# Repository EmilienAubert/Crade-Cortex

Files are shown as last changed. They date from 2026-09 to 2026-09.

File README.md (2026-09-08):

# Crade Cortex

**English** · [Français](README.fr.md)

A DIY MIDI footswitch controller for [PiPedal](https://github.com/rerdavies/pipedal)
with **closed-loop state feedback**: the LEDs and display don't show what your
foot asked for, they show what the Raspberry Pi confirmed.

A Pico running CircuitPython sends MIDI. A Python daemon on the Pi subscribes to
PiPedal's websocket and pushes state back over the same USB cable. One state
exists — PiPedal's — and the whole class of desynchronisation bugs disappears by
construction.

**3D files (.STL and .SLDPRT) are availables in the repo.**

This repository also contains 
[documentation of PiPedal's undocumented internal websocket protocol](docs/en/PROTOCOL.md),
reverse-engineered from version 2.0.110. That is probably the most reusable part
of it for other projects.




---

## What it does

- **4 snapshots** with exclusive selection, confirmed by the Pi
- **Preset changes** with the LED held lit through the NAM model load
- **Tuner** on the display — note and cents, subscribed only on demand
- **16×2 LCD** — pedalboard and snapshot names, boot animation
- **Dead-link detection** — blinking LEDs and an on-screen marker

```
              MIDI CC 102-113 (USB MIDI -> ALSA)
        ┌──────────────────────────────────────────────┐
        │                                              ▼
   ┌─────────┐          ┌──────────────────┐      ┌──────────┐
   │  Pedal  │◄────────►│ pipedal_bridge.py│◄─────│ pipedald │
   │  Pico   │  serial  │     (daemon)     │  ws  │ (PiPedal)│
   └─────────┘          └──────────────────┘      └──────────┘
    S3  N:  T:              A1  A0  ?
```

MIDI does **not** go through the daemon: the Pico talks straight to `pipedald`
via ALSA. The daemon only handles the return path.

---

## Hardware

| Item | Detail |
|---|---|
| Controller | Raspberry Pi Pico (RP2040), CircuitPython |
| Host | Raspberry Pi, PiPedal 2.0.110 |
| Display | LCD1602, HD44780, 4-bit mode |
| Switches | 8 SPST momentary footswitches |
| LEDs | 8, PWM at 2 kHz, one resistor each |

Full wiring, pinout and assembly order: **[docs/en/WIRING.md](docs/en/WIRING.md)**

---

## Installation

### On the Pico

#### 1. Install CircuitPython

Download the `.uf2` for the Raspberry Pi Pico from
[circuitpython.org](https://circuitpython.org/board/raspberry_pi_pico/).

Hold **BOOTSEL** down **before** plugging in the USB cable, then release it. An
`RPI-RP2` drive appears. Drop the `.uf2` onto it: the Pico reboots on its own and
a `CIRCUITPY` drive takes its place.

If the Pico was running different firmware, or if the major version changes, the
install can leave an inconsistent filesystem. In that case run
[`flash_nuke.uf2`](https://learn.adafruit.com/circuitpython-with-raspberry-pi-pico/resetting-flash)
first to wipe the flash completely.

#### 2. Install the libraries

Download the [CircuitPython bundle](https://circuitpython.org/libraries) —
**the one matching your installed major version**. A 9.x bundle on 10.x firmware
produces import errors that are hard to diagnose. The version is written in
`boot_out.txt` at the root of `CIRCUITPY`.

Copy these two folders into `/lib`:

```
lib/
  adafruit_midi/              USB MIDI
  adafruit_character_lcd/     HD44780 driver
```

Whole folders, not just the `.py` files you think you need.

#### 3. Copy the project

To the root of `CIRCUITPY`:

```
boot.py  code.py  ecran.py  retour_pipedal.py
```

On Linux, run `sync` before unplugging. The `CIRCUITPY` filesystem is small and
corrupts easily if a write hasn't finished.

#### 4. Restart

`boot.py` is only re-read on a **hard reset**: unplug and plug back in. Saving
the file is not enough — that's the classic trap.

Saving `code.py`, on the other hand, restarts the program automatically.

#### Checking

`boot_out.txt` holds the CircuitPython version and, when something goes wrong,
the reason it dropped into safe mode. It's the first place to look if the display
stays dark or nothing starts.

```bash
ls /dev/ttyACM*        # two ports should appear: console and data
```

### On the Raspberry Pi

```bash
sudo apt install python3-serial
pip3 install websockets --break-system-packages
```

A udev rule for a stable port name — without it, the `ttyACM` number changes with
plug order:

```
# /etc/udev/rules.d/99-pipedal-pico.rules
SUBSYSTEM=="tty", ATTRS{idVendor}=="239a", ATTRS{product}=="Pedalier", \
  ENV{ID_USB_INTERFACE_NUM}=="02", SYMLINK+="pipedal-pico"
```

```bash
sudo udevadm control --reload && sudo udevadm trigger
python3 pi/pipedal_bridge.py -v
```

A sample systemd unit is provided in `pi/pipedal-bridge.service`.

### MIDI bindings in PiPedal

| System symbol | CC |
|---|---|
| `snapshot1` … `snapshot4` | 102 … 105 |
| `prevProgram` | 110 |
| `nextProgram` | 111 |

CC 112 drives the tuner locally. Binding it to the TooB Tuner's `MUTE` control
lets one press both mute the signal and bring up the tuner.

---

## Documentation

| Document | Contents |
|---|---|
| [docs/en/PROTOCOL.md](docs/en/PROTOCOL.md) | **PiPedal's websocket protocol**, reverse-engineered |
| [docs/en/WIRING.md](docs/en/WIRING.md) | Pinout, wiring, assembly order, checks |
| [docs/en/index.html](docs/en/index.html) | Full documentation, laid out |

---

## The principle

> PiPedal is the single source of truth. The Pico holds no state of its own.

Pressing a switch sends a CC, nothing more. The LED only lights when the Pi's
confirmation arrives. That's what keeps the display honest whatever caused the
change — your foot, the phone, or a `pipedald` restart.

Two safeguards cover link failure, because a closed loop that opens would leave
the LEDs frozen on the last value received:

- **Optimistic fallback at 200 ms** — with no confirmation, the LED lights
  anyway. Degraded, but playable.
- **Heartbeat at 1 Hz** — three missed beats and the active LED blinks, with a
  `!` on the display.

---

## Serial protocol

One ASCII line per event, bidirectional.

| Direction | Frame | Meaning |
|---|---|---|
| Pi → Pico | `S<n>` | Active snapshot, 1-based |
| | `HB` | Heartbeat |
| | `N:<text>` | Pedalboard name |
| | `M:<text>` | Snapshot name |
| | `T:<note>:<cents>` | Tuner |
| Pico → Pi | `A1` / `A0` | Enter / leave tuner mode |
| | `?` | Request full state |

The `?` beacon deserves an explanation: the daemon caches state and only emits on
change. When the Pico restarts, nothing has changed on PiPedal's side — without
this explicit request the pedal would stay blind until the next real change.

---

## Tools

`outils/banc_test_led.py` — a test bench to copy onto a second Pico. Three
looping phases: all LEDs at real brightness so you can match channels, a chase to
identify positions, and full brightness to spot a dead or reversed LED.

Rename it to `code.py` on the test Pico.

---

## A warning about the websocket protocol

PiPedal's websocket API is **internal and undocumented**. This repository
publishes a description captured from version **2.0.110**. It will change between
versions, without notice, and that won't be a bug on PiPedal's side.

If you build on it, pin yourself to a known version and plan to re-verify after
every update.

---

## Licence

MIT. See [LICENSE](LICENSE).

Developed with assistance from Claude (Anthropic). The architecture, the protocol
reverse-engineering and the engineering trade-offs came out of iterative work
between a human and the model.

Source comments are in French.

---

## Acknowledgements

[Robin Davies](https://github.com/rerdavies) for PiPedal, which runs a serious
effects processor on a Raspberry Pi, and whose architecture — a single
server-side model broadcast to every client — is what makes this kind of project
possible at all.

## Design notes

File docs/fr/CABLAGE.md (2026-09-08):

# Crade Cortex — schéma de câblage

[English](../en/WIRING.md) · **Français**

Établi d'après `code.py`. Toute modification d'affectation dans le code doit
être reportée ici, et inversement.

---

## 1. Brochage physique du Pico

Le Pico a 40 broches. La 1 est en haut à gauche, connecteur USB vers le haut.
La numérotation descend à gauche jusqu'à 20, puis remonte à droite de 21 à 40.

```
                    ┌───── USB ─────┐
      S1   GP0  ────┤ 1          40 ├──── VBUS  → LCD 2 et 15
      S2   GP1  ────┤ 2          39 │     VSYS
           GND      │ 3          38 ├──── GND   → rail de masse
      S3   GP2  ────┤ 4          37 │     3V3_EN
      S4   GP3  ────┤ 5          36 │     3V3 OUT   (ne pas utiliser)
    Prst-  GP4  ────┤ 6          35 │     ADC_VREF
    Prst+  GP5  ────┤ 7          34 │     GP28
           GND      │ 8          33 │     AGND
    Accord GP6  ────┤ 9          32 │     GP27
    Libre  GP7  ────┤ 10         31 │     GP26
    LED1   GP8  ────┤ 11         30 │     RUN
    LED2   GP9  ────┤ 12         29 │     GP22
           GND      │ 13         28 │     GND
  LCD RS   GP10 ────┤ 14         27 ├──── GP21   LED8
  LCD E    GP11 ────┤ 15         26 ├──── GP20   LED7
  LCD D4   GP12 ────┤ 16         25 ├──── GP19   LED6
  LCD D5   GP13 ────┤ 17         24 ├──── GP18   LED5
           GND      │ 18         23 │     GND
  LCD D6   GP14 ────┤ 19         22 ├──── GP17   LED4
  LCD D7   GP15 ────┤ 20         21 ├──── GP16   LED3
                    └───────────────┘
```

**22 broches utilisées sur 26 disponibles.** Restent libres : `GP22`, `GP26`,
`GP27`, `GP28`.

> **Ne jamais alimenter le LCD depuis la broche 36 (3V3).** Il lui faut du 5 V,
> donc la broche 40 (VBUS). Un HD44780 en 3,3 V ne s'allume pas ou affiche
> n'importe quoi.

---

## 2. Table de correspondance

| GPIO | Broche physique | Fonction |
|---|---|---|
| `GP0` | 1 | Switch S1 |
| `GP1` | 2 | Switch S2 |
| `GP2` | 4 | Switch S3 |
| `GP3` | 5 | Switch S4 |
| `GP4` | 6 | Switch F1 — preset précédent |
| `GP5` | 7 | Switch F2 — preset suivant |
| `GP6` | 9 | Switch F3 — accordeur |
| `GP7` | 10 | Switch F4 — libre |
| `GP8` | 11 | LED 1 |
| `GP9` | 12 | LED 2 |
| `GP10` | 14 | LCD — RS |
| `GP11` | 15 | LCD — E |
| `GP12` | 16 | LCD — D4 |
| `GP13` | 17 | LCD — D5 |
| `GP14` | 19 | LCD — D6 |
| `GP15` | 20 | LCD — D7 |
| `GP16` | 21 | LED 3 |
| `GP17` | 22 | LED 4 |
| `GP18` | 24 | LED 5 |
| `GP19` | 25 | LED 6 |
| `GP20` | 26 | LED 7 |
| `GP21` | 27 | LED 8 |
| — | 38 | GND — rail de masse |
| — | 40 | VBUS — 5 V vers le LCD |

LED 1 et 2 sont à gauche, LED 3 à 8 à droite : c'est un héritage du câblage
initial sur `GP8`/`GP9`. Les déplacer ne servirait qu'à l'esthétique du faisceau,
et obligerait à recâbler ce qui fonctionne déjà.

---

## 2 bis. Disposition sur la face

Deux rangées de quatre, de gauche à droite. Le rang avant est celui qu'on
utilise le plus : il doit être le plus proche du bord.

```
   arriere   [ Preset - ] [ Preset + ] [ Accordeur ] [ Libre ]
                 GP4          GP5          GP6         GP7
                 CC 110       CC 111       CC 112      CC 113

   avant     [    S1    ] [    S2    ] [    S3     ] [   S4   ]
                 GP0          GP1          GP2         GP3
                 CC 102       CC 103       CC 104      CC 105
```

**Les LED se placent au-dessus des switches, jamais en dessous.** Le pied masque
la zone basse pendant l'appui : une LED sous le switch n'est visible qu'une fois
le pied retiré, c'est-à-dire trop tard.

**Au moins 25 mm entre les axes des deux rangées**, 40 mm si la place le permet.
En dessous, le talon accroche le rang arrière quand on appuie sur le rang avant.

Le boîtier passe de 27 mm à l'avant à 63 mm à l'arrière. Le rang arrière tombe
donc sur une zone plus épaisse et plus inclinée : vérifie qu'il reste assez de
hauteur sous la face pour le corps du footswitch et ses cosses, souvent 25 à
30 mm avec le fil.

### Bindings PiPedal correspondants

| Symbole système | CC |
|---|---|
| `snapshot1` … `snapshot4` | 102 … 105 |
| `prevProgram` | 110 |
| `nextProgram` | 111 |

Optionnel : lier le CC 112 au contrôle `MUTE` du TooB Tuner, pour couper le son
et afficher l'accordeur d'un seul geste.

---

## 3. Le rail de masse

Dix-neuf connexions vont à la masse : huit switches, huit LED, trois broches du
LCD. Les souder toutes sur la broche 38 est impossible.

**Fabrique un rail.** Un fil de cuivre nu, ou une piste de plaque à trous,
courant sur toute la longueur du montage. Une seule liaison le relie à la
broche 38 du Pico. Chaque masse individuelle vient s'y souder à l'endroit le plus
proche.

```
   broche 38 ────┬──────┬──────┬──────┬──────┬──────┬─────
                 │      │      │      │      │      │
              LCD 1   LED1   LED2    S1     S2    LED3  …
              LCD 5
              LCD 16
```

**Ce qu'il faut éviter, c'est le chaînage** — LED1 vers LED2 vers LED3 vers le
Pico. Électriquement ça marcherait à 50 mA, mais un faux contact au milieu de la
chaîne fait tomber tout ce qui est derrière, et tu passes la soirée à chercher.

Le rail donne un point de défaillance unique et identifiable au lieu de dix-neuf
points en série.

---

## 4. Les switches

Aucune résistance. Le pull-up interne du Pico est activé par le code
(`digitalio.Pull.UP`), les switches sont actifs à l'état bas.

```
   GPx ────────────○ ○──────────── rail de masse
                switch
```

| Switch | Vers |
|---|---|
| S1 | broche 1 et masse |
| S2 | broche 2 et masse |
| S3 | broche 4 et masse |
| S4 | broche 5 et masse |
| F1 — preset − | broche 6 et masse |
| F2 — preset + | broche 7 et masse |
| F3 — accordeur | broche 9 et masse |
| F4 — libre | broche 10 et masse |

Les footswitches à trois cosses sont souvent des inverseurs : utilise la cosse
commune et l'une des deux autres. Vérifie au multimètre quelle paire se ferme à
l'appui.

**Laisse le fil arriver détendu sur la cosse.** C'est elle qui encaisse la
contrainte mécanique de l'appui, transmise par le corps du switch. Un fil tendu
sur une soudure finit par lâcher, bien avant que le fil lui-même ne fatigue.

---

## 5. Les LED

Une résistance **par LED**, jamais partagée : une résistance commune fait varier
la luminosité selon le nombre de LED allumées.

```
   GPx ─────[ 330 Ω ]─────▶|───── rail de masse
                        anode  cathode
```

La patte longue est l'anode, côté résistance. La patte courte, et le méplat sur
le boîtier, indiquent la cathode, côté masse.

| LED | Broche |
|---|---|
| LED 1 | 11 |
| LED 2 | 12 |
| LED 3 | 21 |
| LED 4 | 22 |
| LED 5 | 24 |
| LED 6 | 25 |
| LED 7 | 26 |
| LED 8 | 27 |

### Sur la valeur de résistance

Avec 330 Ω et une LED rouge, la sortie 3,3 V du Pico débite environ 4 mA de
crête. Le code applique en plus un PWM à 12 %, ce qui donne une luminosité
volontairement basse.

Si c'est trop sombre sur scène, deux leviers dans cet ordre : **monte
`BRILLANCE`** dans `code.py`, c'est gratuit et réversible. Ensuite seulement,
descends à 220 Ω. Ne va pas sous 150 Ω : une broche du Pico est limitée à 12 mA.

> **Les LED bleues et blanches sont un cas à part.** Leur tension de seuil est de
> 3,0 à 3,2 V, soit presque le 3,3 V du Pico. Elles seront très sombres quelle
> que soit la résistance. Reste sur du rouge, du jaune ou du vert classique.

---

## 6. Le LCD1602

| Broche LCD | Vers |
|---|---|
| 1 VSS | rail de masse |
| 2 VDD | broche 40 — VBUS, 5 V |
| 3 V0 | curseur du potentiomètre |
| 4 RS | broche 14 |
| 5 R/W | **rail de masse** |
| 6 E | broche 15 |
| 7–10 D0–D3 | **rien**, mode 4 bits |
| 11 D4 | broche 16 |
| 12 D5 | broche 17 |
| 13 D6 | broche 19 |
| 14 D7 | broche 20 |
| 15 A | broche 40 — VBUS |
| 16 K | rail de masse |

### Potentiomètre de contraste

10 kΩ, trois pattes. Celle du **milieu** est le curseur.

```
   VBUS ──────┤ │ │├────── rail de masse
               └─┬─┘
                 └──────── LCD broche 3
```

Les deux extérieures sont interchangeables : les inverser inverse seulement le
sens de rotation.

**Sans lui, l'écran est soit tout noir, soit tout vide.** C'est la première cause
de « mon LCD ne marche pas ».

### Trois points qui comptent

**R/W impérativement à la masse.** Le LCD passe en écriture seule et ne peut plus
renvoyer du 5 V vers une entrée du Pico. C'est ce qui rend le mélange 5 V / 3,3 V
sans danger sur ce montage.

**Pas de résistance sur la broche 15.** Le module QAPASS 1602A porte déjà R8,
marquée `101`, soit 100 Ω, au dos près de la broche K. Sur un autre modèle,
vérifie avant de brancher — sinon 220 Ω en série.

**Ponte sur place.** Les broches 1, 5 et 16 vont toutes à la masse : relie-les
entre elles directement sur le LCD, un seul fil en sort. Pareil pour 2 et 15 vers
le VBUS. Tu passes de dix fils à huit, et le potentiomètre se monte à cheval sur
les broches 1, 2 et 3 sans fil volant.

---

## 7. Le Pico sur la plaque

Ne soude pas les fils directement sur le Pico. Soude **deux barrettes femelles
sur la plaque à trous**, et enfiche le Pico dedans. Tout le câblage arrive sur la
plaque, jamais sur la carte.

Le jour où tu veux remplacer le Pico, corriger une affectation ou le récupérer
pour autre chose, tu le retires d'un geste. Vingt fils soudés sur des pastilles
serrées, c'est une heure de dessoudage et une pastille arrachée.

Les barrettes coûtent 8 mm de hauteur. Si ton boîtier est serré à l'avant — 27 mm
seulement — souder le Pico à plat sur la plaque reste un compromis acceptable :
la plaque, elle, demeure modifiable.

**Soude les barrettes avec le Pico enfiché dedans.** Ça les maintient d'équerre.
À main levée elles partent de travers et n'entrent plus nulle part.

---

## 8. Ordre de montage

Chaque étape se teste avant de passer à la suivante.

1. **Le rail de masse et la liaison vers la broche 38.** Vérifie la continuité au
   multimètre entre les deux extrémités du rail.
2. **Le VBUS.** Contrôle l'absence de continuité entre le rail de masse et le
   5 V — un court ici empêcherait le Pico de démarrer.
3. **Le LCD**, potentiomètre compris. Au branchement, des rectangles noirs
   doivent apparaître : c'est la preuve qu'il est alimenté et vivant. Tourne le
   potentiomètre jusqu'à ce qu'ils s'estompent.
4. **Les LED, une par une.** Teste chacune avec
   `printf 'S1\n' > /dev/pipedal-pico` et ses variantes.
5. **Les switches, un par un.** `aseqdump -p XX:0` sur le Pi montre les CC qui
   partent.

---

## 9. Vérifications au multimètre

Pico débranché, avant la première mise sous tension :

| Test | Attendu |
|---|---|
| Rail de masse ↔ broche 38 | continuité |
| Broche 38 ↔ broche 40 | **pas** de continuité |
| Chaque cathode de LED ↔ rail | continuité |
| Chaque anode de LED ↔ sa broche | ~330 Ω |
| LCD 1, 5, 16 ↔ rail | continuité |
| LCD 2, 15 ↔ broche 40 | continuité |
| Deux broches GPIO voisines | **pas** de continuité |

Le dernier test attrape les ponts de soudure, qui sont la panne la plus courante
et la plus difficile à voir à l'œil nu sur une plaque à trous.

---

## 10. Récapitulatif des fils

| Destination | Fils vers la plaque |
|---|---|
| 8 switches | 8 signaux + 8 masses |
| 8 LED | 8 signaux + 8 masses |
| LCD | 6 signaux + 1 masse + 1 alim |
| Potentiomètre | 3 |
| **Total** | **42** |

Le fil monobrin de câble Cat 6 (23 AWG, 0,26 mm²) convient parfaitement : il
encaisse plusieurs ampères là où le montage en consomme 50 mA, il tient dans une
breadboard, son isolant supporte le fer, et les huit couleurs facilitent le
repérage.

Fixe une convention et note-la — masse en marron, 5 V en orange, par exemple.
Dans six mois, en rouvrant le boîtier, tu seras content de ne pas avoir à sonner
chaque fil.

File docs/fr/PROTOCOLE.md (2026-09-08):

# Protocole websocket de PiPedal

[English](../en/PROTOCOL.md) · **Français**

Relevé par capture sur **PiPedal 2.0.110**, côté navigateur.

> **API interne, non documentée par le projet.** Elle changera d'une version à
> l'autre. Épingle-toi à une version connue et revérifie après chaque mise à
> jour. Rien de ce qui suit n'est un contrat.

**Endpoint :** `ws://<hôte>:80/pipedal`

Le port par défaut est 80 sur Raspberry Pi OS. Sous Ubuntu, PiPedal bascule
généralement sur le 81, Apache occupant le 80. `pipedalconfig` permet de le
changer.

---

## Enveloppe

Tableau JSON à un ou deux éléments : `[entête]` ou `[entête, corps]`.

```jsonc
// requête sans argument
[{"message": "hello", "replyTo": 2}]

// requête avec argument
[{"message": "monitorPort", "replyTo": 24},
 {"instanceId": 16, "key": "FREQ", "updateRate": 0.05}]

// réponse du serveur
[{"reply": 2, "message": "ehlo"}, 20]
```

Deux champs, jamais ensemble :

- **`replyTo`** — « réponds-moi avec cet identifiant ». Présent sur les requêtes
  du client, et sur les messages poussés par le serveur qui attendent un accusé.
- **`reply`** — « ceci est la réponse à cet identifiant ».

Ce n'est **pas** du JSON-RPC 2.0. L'implémentation est un proxy d'objet distant
écrit à la main, entre `PiPedalModel.tsx` côté client et `PiPedalModel.cpp` côté
serveur.

---

## Poignée de main

**Le client doit envoyer `hello` dès la connexion.**

```jsonc
[{"message": "hello", "replyTo": 2}]
[{"reply": 2, "message": "ehlo"}, 20]
```

Sans lui, le serveur accepte la connexion, répond aux requêtes, et **ne diffuse
jamais rien**. C'est un échec silencieux : tout semble fonctionner jusqu'à ce
qu'on remarque qu'aucun événement n'arrive.

---

## Accusés de réception

Quand l'entête d'un message poussé contient `replyTo`, le client doit répondre :

```jsonc
[{"replyTo": 996, "message": "onVuUpdate"}, { … }]
[{"reply": 996, "message": "onVuUpdate"}, true]
```

C'est du contrôle de flux : le serveur numérote, attend l'accusé, et n'envoie la
suite qu'après. Un client qui n'acquitte pas finit par ne plus rien recevoir.

`onPedalboardChanged` n'a pas de `replyTo` et ne demande donc rien.

---

## État du pedalboard

### Diffusion sur changement

Émise à **tous** les clients connectés, y compris celui qui a provoqué le
changement. C'est ce qui permet à un contrôleur physique de confirmer ses propres
actions.

```jsonc
[{"message": "onPedalboardChanged"},
 {"clientId": -1,
  "pedalboard": {
    "name": "Fender Clean",
    "selectedSnapshot": 1,        // BASE 0
    "selectedPlugin": 16,
    "items": [
      {"instanceId": 16,
       "uri": "http://two-play.com/plugins/toob-tuner",
       "isEnabled": true,
       "controlValues": [{"key": "MUTE", "value": 0}, …],
       "midiBindings": [ … ]},
      …
    ],
    "snapshots": [
      {"name": "Default", "color": "purple", "isModified": false,
       "values": [ … ]},
      null, null, null, null
    ]
  }}]
```

Points à connaître :

- **`selectedSnapshot` est en base 0.**
- **`snapshots` contient des trous** (`null`) pour les emplacements vides. Ne pas
  supposer que l'index est valide.
- **Chaque diffusion pèse ~9 ko** : le pedalboard entier est renvoyé, pas
  seulement ce qui a changé. Relever `max_size` sur la connexion.
- **`isModified`** indique un snapshot édité mais non sauvegardé.
- **`color`** donne la couleur du snapshot telle qu'affichée dans l'UI.

### État initial

```jsonc
[{"message": "currentPedalboard", "replyTo": 8}]
```

La réponse place le pedalboard **à la racine du corps**, pas sous une clé
`pedalboard` comme dans la diffusion :

```jsonc
[{"reply": 8, "message": "currentPedalboard"},
 {"name": "Fender Clean", "selectedSnapshot": 0, "items": [ … ]}]
```

### Commande

```jsonc
[{"message": "setSnapshot"}, 0]
```

---

## Ports de monitoring

Permet de suivre en continu la valeur d'un port de sortie LV2.

```jsonc
[{"message": "monitorPort", "replyTo": 24},
 {"instanceId": 16, "key": "FREQ", "updateRate": 0.05}]

// la reponse porte le handle d'abonnement
[{"reply": 24, "message": "monitorPort"}, 29]

// puis, periodiquement
[{"replyTo": 2, "message": "onMonitorPortOutput"},
 {"subscriptionHandle": 29, "value": 40.12}]

// desabonnement
[{"message": "unmonitorPort"}, 29]
```

`updateRate` est une **période en secondes**, pas une fréquence. Le client web
utilise 0,0333 (30 Hz) et 0,0667 (15 Hz).

### Exemple : accordeur

Le plugin **TooB Tuner** (`http://two-play.com/plugins/toob-tuner`) expose un
port `FREQ` qui donne un **numéro de note MIDI flottant**, `-1` en l'absence de
signal.

```python
NOTES = ("C", "C#", "D", "D#", "E", "F", "F#", "G", "G#", "A", "A#", "B")

def note_et_cents(valeur):
    if valeur is None or valeur < 0:
        return (None, 0)
    entier = int(round(valeur))
    cents = int(round((valeur - entier) * 100))
    return (NOTES[entier % 12] + str(entier // 12 - 1), cents)
```

**Ne jamais coder l'`instanceId` en dur.** Elle change avec le pedalboard. La
retrouver dans `items` en cherchant l'URI du plugin, et se réabonner quand elle
bouge.

### Autres ports intéressants

Relevés dans le descripteur `plugins` :

| Plugin | Port de sortie | Contenu |
|---|---|---|
| TooB Neural Amp Modeler | `gateOut` | État du noise gate, 0 ou 1 |
| TooB NAM | `inputGainOut` | Niveau d'entrée en dB |
| Gxdigital_delay | `DD_NOTIFY` | Tempo en BPM |
| TooB 4Looper | `position1` | Position dans la boucle, 0 à 1 |
| TooB 4Looper | `record_led1`, `play_led1` | État d'enregistrement et lecture |
| TooB 4Looper | `bar_led`, `beat_led` | Mesures et temps |
| TooB File Player | `position`, `duration`, `state` | Lecture de fichier |

---

## VU-mètres

```jsonc
[{"message": "addVuSubscription", "replyTo": 23}, 16]
[{"reply": 23, "message": "addVuSubscription"}, 28]

[{"replyTo": 996, "message": "onVuUpdate"},
 {"instanceId": 16, "sampleTime": 2741501184,
  "isStereoInput": false, "isStereoOutput": false,
  "inputMaxValueL": 6.55e-05, "inputMaxValueR": 0,
  "outputMaxValueL": 6.55e-05, "outputMaxValueR": 0}]
```

Ces messages **exigent un accusé**. Le flux est nourri : ne s'y abonner qu'en cas
de besoin réel.

---

## Bindings MIDI système

```jsonc
[{"message": "getSystemMidiBindings", "replyTo": 22}]
```

Les symboles disponibles :

```
prevBank      nextBank
prevProgram   nextProgram
snapshot1 … snapshot6
prevSnapshot  nextSnapshot
startHotspot  stopHotspot
shutdown      reboot
```

`shutdown` et `reboot` permettent d'arrêter proprement le Raspberry Pi depuis un
footswitch. Ce n'est pas anecdotique : couper l'alimentation sans arrêt propre
peut faire perdre presets, banques et configuration.

Structure d'un binding :

```jsonc
{"channel": -1, "symbol": "snapshot1", "bindingType": 2,
 "note": 72, "control": 102,
 "minControlValue": 0, "maxControlValue": 127,
 "minValue": 0, "maxValue": 1,
 "rotaryScale": 1, "linearControlType": 0, "switchControlType": 0}
```

`bindingType` vaut 0 quand le binding est inactif, 2 pour un contrôle MIDI CC.

---

## Autres messages observés

| Message | Contenu |
|---|---|
| `version` | Version serveur, OS, adresses web |
| `plugins` | Descripteur complet de tous les plugins LV2 — volumineux |
| `pluginClasses` | Taxonomie des types de plugins |
| `getPresets` | Liste des presets avec `instanceId` et nom |
| `getBankIndex` | Banques disponibles et banque sélectionnée |
| `getJackConfiguration` | Fréquence, taille de buffer, ports audio et MIDI |
| `getJackServerSettings` | Périphérique ALSA, buffers |
| `getUpdateStatus` | Mise à jour disponible |
| `getShowStatusMonitor` | Affichage du moniteur système |
| `imageList` | Ressources graphiques de l'UI |
| `getFavorites`, `getWifiConfigSettings`, `getGovernorSettings` | Configuration |

---

## Séquence d'ouverture du client web

Pour référence, l'ordre observé au chargement de la page :

```
getWifiRegulatoryDomains → hello → imageList → version → getUpdateStatus
→ getHasWifi → plugins → currentPedalboard → pluginClasses → getPresets
→ getWifiConfigSettings → … → getSystemMidiBindings
→ addVuSubscription → monitorPort ×4
```

Un client minimal n'a besoin que de `hello` puis `currentPedalboard`.

---

## Implémentation de référence

`pi/pipedal_bridge.py` dans ce dépôt : environ 400 lignes, avec reconnexion,
accusés, abonnement conditionnel et limitation de débit.

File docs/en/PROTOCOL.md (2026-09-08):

# PiPedal websocket protocol

**English** · [Français](../fr/PROTOCOLE.md)

Captured from **PiPedal 2.0.110**, on the browser side.

> **Internal API, undocumented by the project.** It will change between versions.
> Pin yourself to a known version and re-verify after every update. Nothing below
> is a contract.

**Endpoint:** `ws://<host>:80/pipedal`

Port 80 is the default on Raspberry Pi OS. On Ubuntu, PiPedal usually falls back
to 81 because Apache holds 80. `pipedalconfig` can change it.

---

## Envelope

A JSON array of one or two elements: `[header]` or `[header, body]`.

```jsonc
// request with no argument
[{"message": "hello", "replyTo": 2}]

// request with an argument
[{"message": "monitorPort", "replyTo": 24},
 {"instanceId": 16, "key": "FREQ", "updateRate": 0.05}]

// server response
[{"reply": 2, "message": "ehlo"}, 20]
```

Two fields, never together:

- **`replyTo`** — "answer me with this id". Present on client requests, and on
  server-pushed messages that expect an acknowledgement.
- **`reply`** — "this is the answer to that id".

This is **not** JSON-RPC 2.0. The implementation is a hand-written remote-object
proxy between `PiPedalModel.tsx` on the client and `PiPedalModel.cpp` on the
server.

---

## Handshake

**The client must send `hello` on connect.**

```jsonc
[{"message": "hello", "replyTo": 2}]
[{"reply": 2, "message": "ehlo"}, 20]
```

Without it the server accepts the connection, answers requests, and **never
broadcasts anything**. It's a silent failure: everything looks fine until you
notice no events ever arrive.

---

## Acknowledgements

When a pushed message's header carries `replyTo`, the client must answer:

```jsonc
[{"replyTo": 996, "message": "onVuUpdate"}, { … }]
[{"reply": 996, "message": "onVuUpdate"}, true]
```

This is flow control: the server numbers each message, waits for the ack, and
only then sends the next. A client that doesn't acknowledge eventually stops
receiving anything.

`onPedalboardChanged` has no `replyTo` and expects nothing.

---

## Pedalboard state

### Change broadcast

Sent to **every** connected client, including the one that caused the change.
That's what lets a physical controller confirm its own actions.

```jsonc
[{"message": "onPedalboardChanged"},
 {"clientId": -1,
  "pedalboard": {
    "name": "Fender Clean",
    "selectedSnapshot": 1,        // ZERO-BASED
    "selectedPlugin": 16,
    "items": [
      {"instanceId": 16,
       "uri": "http://two-play.com/plugins/toob-tuner",
       "isEnabled": true,
       "controlValues": [{"key": "MUTE", "value": 0}, …],
       "midiBindings": [ … ]},
      …
    ],
    "snapshots": [
      {"name": "Default", "color": "purple", "isModified": false,
       "values": [ … ]},
      null, null, null, null
    ]
  }}]
```

Things worth knowing:

- **`selectedSnapshot` is zero-based.**
- **`snapshots` contains holes** (`null`) for empty slots. Don't assume the index
  is valid.
- **Each broadcast is around 9 kB**: the entire pedalboard is resent, not just
  what changed. Raise `max_size` on the connection.
- **`isModified`** flags a snapshot that has been edited but not saved.
- **`color`** is the snapshot colour as shown in the UI.

### Initial state

```jsonc
[{"message": "currentPedalboard", "replyTo": 8}]
```

The response puts the pedalboard **at the root of the body**, not under a
`pedalboard` key as the broadcast does:

```jsonc
[{"reply": 8, "message": "currentPedalboard"},
 {"name": "Fender Clean", "selectedSnapshot": 0, "items": [ … ]}]
```

### Command

```jsonc
[{"message": "setSnapshot"}, 0]
```

---

## Port monitoring

Streams the value of an LV2 output port.

```jsonc
[{"message": "monitorPort", "replyTo": 24},
 {"instanceId": 16, "key": "FREQ", "updateRate": 0.05}]

// the response carries the subscription handle
[{"reply": 24, "message": "monitorPort"}, 29]

// then, periodically
[{"replyTo": 2, "message": "onMonitorPortOutput"},
 {"subscriptionHandle": 29, "value": 40.12}]

// unsubscribe
[{"message": "unmonitorPort"}, 29]
```

`updateRate` is a **period in seconds**, not a frequency. The web client uses
0.0333 (30 Hz) and 0.0667 (15 Hz).

### Example: the tuner

The **TooB Tuner** plugin (`http://two-play.com/plugins/toob-tuner`) exposes a
`FREQ` port carrying a **floating-point MIDI note number**, or `-1` when there is
no signal.

```python
NOTES = ("C", "C#", "D", "D#", "E", "F", "F#", "G", "G#", "A", "A#", "B")

def note_and_cents(value):
    if value is None or value < 0:
        return (None, 0)
    n = int(round(value))
    cents = int(round((value - n) * 100))
    return (NOTES[n % 12] + str(n // 12 - 1), cents)
```

**Never hard-code the `instanceId`.** It changes with the pedalboard. Find it in
`items` by matching the plugin URI, and re-subscribe when it moves.

### Other useful output ports

Taken from the `plugins` descriptor:

| Plugin | Output port | Contents |
|---|---|---|
| TooB Neural Amp Modeler | `gateOut` | Noise gate state, 0 or 1 |
| TooB NAM | `inputGainOut` | Input level in dB |
| Gxdigital_delay | `DD_NOTIFY` | Tempo in BPM |
| TooB 4Looper | `position1` | Position within the loop, 0 to 1 |
| TooB 4Looper | `record_led1`, `play_led1` | Record and play state |
| TooB 4Looper | `bar_led`, `beat_led` | Bars and beats |
| TooB File Player | `position`, `duration`, `state` | File playback |

---

## VU meters

```jsonc
[{"message": "addVuSubscription", "replyTo": 23}, 16]
[{"reply": 23, "message": "addVuSubscription"}, 28]

[{"replyTo": 996, "message": "onVuUpdate"},
 {"instanceId": 16, "sampleTime": 2741501184,
  "isStereoInput": false, "isStereoOutput": false,
  "inputMaxValueL": 6.55e-05, "inputMaxValueR": 0,
  "outputMaxValueL": 6.55e-05, "outputMaxValueR": 0}]
```

These messages **require an acknowledgement**. The stream is dense: only
subscribe when you actually need it.

---

## System MIDI bindings

```jsonc
[{"message": "getSystemMidiBindings", "replyTo": 22}]
```

Available symbols:

```
prevBank      nextBank
prevProgram   nextProgram
snapshot1 … snapshot6
prevSnapshot  nextSnapshot
startHotspot  stopHotspot
shutdown      reboot
```

`shutdown` and `reboot` let a footswitch shut the Raspberry Pi down cleanly.
That's not a detail: cutting power without an orderly shutdown can lose presets,
banks and configuration.

Binding structure:

```jsonc
{"channel": -1, "symbol": "snapshot1", "bindingType": 2,
 "note": 72, "control": 102,
 "minControlValue": 0, "maxControlValue": 127,
 "minValue": 0, "maxValue": 1,
 "rotaryScale": 1, "linearControlType": 0, "switchControlType": 0}
```

`bindingType` is 0 when the binding is inactive, 2 for a MIDI CC control.

---

## Other observed messages

| Message | Contents |
|---|---|
| `version` | Server version, OS, web addresses |
| `plugins` | Full descriptor of every LV2 plugin — very large |
| `pluginClasses` | Plugin type taxonomy |
| `getPresets` | Preset list with `instanceId` and name |
| `getBankIndex` | Available banks and current selection |
| `getJackConfiguration` | Sample rate, buffer size, audio and MIDI ports |
| `getJackServerSettings` | ALSA device, buffers |
| `getUpdateStatus` | Update availability |
| `getShowStatusMonitor` | System monitor display setting |
| `imageList` | UI graphic assets |
| `getFavorites`, `getWifiConfigSettings`, `getGovernorSettings` | Configuration |

---

## Web client startup sequence

For reference, the order observed when the page loads:

```
getWifiRegulatoryDomains → hello → imageList → version → getUpdateStatus
→ getHasWifi → plugins → currentPedalboard → pluginClasses → getPresets
→ getWifiConfigSettings → … → getSystemMidiBindings
→ addVuSubscription → monitorPort ×4
```

A minimal client only needs `hello` then `currentPedalboard`.

---

## Reference implementation

`pi/pipedal_bridge.py` in this repository: around 400 lines, with reconnection,
acknowledgements, conditional subscription and rate limiting. Comments are in
French.

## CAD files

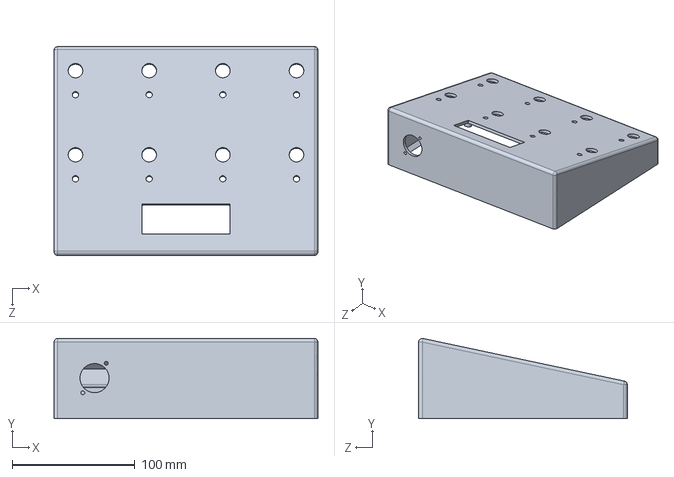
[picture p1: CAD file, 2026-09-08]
3D model/Solidworks/case.SLDPRT
215.0 x 65.3 x 170.0 mm

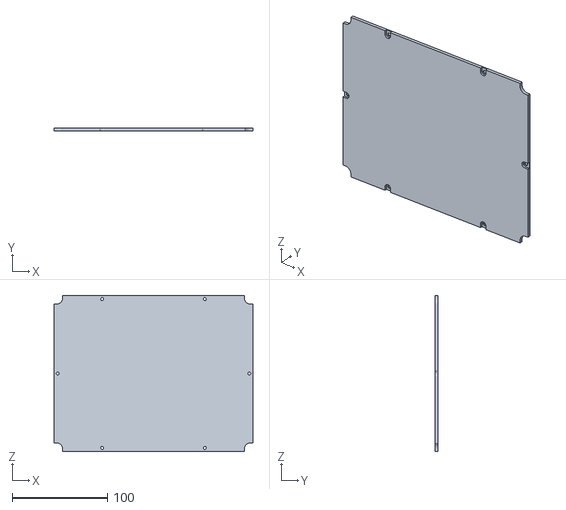
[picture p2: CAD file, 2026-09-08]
3D model/STL/lid.STL
208.6 x 3.00 x 163.6

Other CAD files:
3D model/STL/enclosure.STL

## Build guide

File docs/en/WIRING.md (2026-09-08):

# Crade Cortex — wiring

**English** · [Français](../fr/CABLAGE.md)

Derived from `code.py`. Any change to the pin assignment in the code must be
reflected here, and the other way round.

---

## 1. Pico physical pinout

The Pico has 40 pins. Pin 1 is top-left with the USB connector facing up.
Numbering runs down the left side to 20, then back up the right side from 21 to
40.

```
                    ┌───── USB ─────┐
      S1   GP0  ────┤ 1          40 ├──── VBUS  → LCD 2 and 15
      S2   GP1  ────┤ 2          39 │     VSYS
           GND      │ 3          38 ├──── GND   → ground rail
      S3   GP2  ────┤ 4          37 │     3V3_EN
      S4   GP3  ────┤ 5          36 │     3V3 OUT   (do not use)
   Prst-   GP4  ────┤ 6          35 │     ADC_VREF
   Prst+   GP5  ────┤ 7          34 │     GP28
           GND      │ 8          33 │     AGND
   Tuner   GP6  ────┤ 9          32 │     GP27
   Spare   GP7  ────┤ 10         31 │     GP26
    LED1   GP8  ────┤ 11         30 │     RUN
    LED2   GP9  ────┤ 12         29 │     GP22
           GND      │ 13         28 │     GND
  LCD RS   GP10 ────┤ 14         27 ├──── GP21   LED8
  LCD E    GP11 ────┤ 15         26 ├──── GP20   LED7
  LCD D4   GP12 ────┤ 16         25 ├──── GP19   LED6
  LCD D5   GP13 ────┤ 17         24 ├──── GP18   LED5
           GND      │ 18         23 │     GND
  LCD D6   GP14 ────┤ 19         22 ├──── GP17   LED4
  LCD D7   GP15 ────┤ 20         21 ├──── GP16   LED3
                    └───────────────┘
```

**22 pins used out of 26 available.** Free: `GP22`, `GP26`, `GP27`, `GP28`.

> **Never power the LCD from pin 36 (3V3).** It needs 5 V, so pin 40 (VBUS). An
> HD44780 on 3.3 V either stays dark or shows garbage.

---

## 2. Pin map

| GPIO | Physical pin | Function |
|---|---|---|
| `GP0` | 1 | Switch S1 |
| `GP1` | 2 | Switch S2 |
| `GP2` | 4 | Switch S3 |
| `GP3` | 5 | Switch S4 |
| `GP4` | 6 | Switch F1 — previous preset |
| `GP5` | 7 | Switch F2 — next preset |
| `GP6` | 9 | Switch F3 — tuner |
| `GP7` | 10 | Switch F4 — spare |
| `GP8` | 11 | LED 1 |
| `GP9` | 12 | LED 2 |
| `GP10` | 14 | LCD — RS |
| `GP11` | 15 | LCD — E |
| `GP12` | 16 | LCD — D4 |
| `GP13` | 17 | LCD — D5 |
| `GP14` | 19 | LCD — D6 |
| `GP15` | 20 | LCD — D7 |
| `GP16` | 21 | LED 3 |
| `GP17` | 22 | LED 4 |
| `GP18` | 24 | LED 5 |
| `GP19` | 25 | LED 6 |
| `GP20` | 26 | LED 7 |
| `GP21` | 27 | LED 8 |
| — | 38 | GND — ground rail |
| — | 40 | VBUS — 5 V to the LCD |

LEDs 1 and 2 sit on the left side while LEDs 3 to 8 are on the right. That's
inherited from the original `GP8`/`GP9` wiring. Moving them would only tidy the
loom, at the cost of rewiring something that already works.

---

## 3. Front-panel layout

Two rows of four, left to right. The front row is the one you use most, so it
goes closest to the edge.

```
   back    [ Preset - ] [ Preset + ] [   Tuner   ] [ Spare  ]
                GP4          GP5          GP6         GP7
                CC 110       CC 111       CC 112      CC 113

   front   [    S1    ] [    S2    ] [    S3     ] [   S4   ]
                GP0          GP1          GP2         GP3
                CC 102       CC 103       CC 104      CC 105
```

**LEDs go above the switches, never below.** Your foot covers the lower area
during the press: an LED below the switch is only visible once you lift off,
which is too late.

**At least 25 mm between the two rows**, measured centre to centre; 40 mm if
there's room. Below that, your heel catches the back row while pressing the front
one.

### Matching PiPedal bindings

| System symbol | CC |
|---|---|
| `snapshot1` … `snapshot4` | 102 … 105 |
| `prevProgram` | 110 |
| `nextProgram` | 111 |

Optional: bind CC 112 to the TooB Tuner's `MUTE` control so one press both mutes
and brings up the tuner.

---

## 4. The ground rail

Nineteen connections go to ground: eight switches, eight LEDs, three LCD pins.
Soldering them all to pin 38 isn't practical.

**Build a rail.** A bare copper wire, or a track on stripboard, running the length
of the assembly. A single link ties it to pin 38. Each individual ground joins it
at the nearest point.

```
     pin 38 ────┬──────┬──────┬──────┬──────┬──────┬─────
                │      │      │      │      │      │
             LCD 1   LED1   LED2    S1     S2    LED3  …
             LCD 5
             LCD 16
```

**What you want to avoid is daisy-chaining** — LED1 to LED2 to LED3 to the Pico.
Electrically it would work at 50 mA, but one bad joint halfway along takes
everything downstream with it, and you lose an evening finding it.

The rail gives you one identifiable failure point instead of nineteen in series.

---

## 5. The switches

No resistors. The Pico's internal pull-ups are enabled in code
(`digitalio.Pull.UP`), so the switches are active-low.

```
   GPx ────────────○ ○──────────── ground rail
                 switch
```

| Switch | To |
|---|---|
| S1 | pin 1 and ground |
| S2 | pin 2 and ground |
| S3 | pin 4 and ground |
| S4 | pin 5 and ground |
| F1 — preset − | pin 6 and ground |
| F2 — preset + | pin 7 and ground |
| F3 — tuner | pin 9 and ground |
| F4 — spare | pin 10 and ground |

Three-lug footswitches are often changeover types: use the common lug and one of
the others. Check with a multimeter which pair closes on press.

**Let the wire reach the lug slack.** The lug takes the mechanical load of the
press, transmitted through the switch body. A wire under tension on a joint
eventually fails, long before the wire itself fatigues.

---

## 6. The LEDs

One resistor **per LED**, never shared: a common resistor makes brightness vary
with how many LEDs are lit.

```
   GPx ─────[ 330 Ω ]─────▶|───── ground rail
                        anode  cathode
```

The long leg is the anode, resistor side. The short leg — and the flat on the
housing — mark the cathode, ground side.

| LED | Pin |
|---|---|
| LED 1 | 11 |
| LED 2 | 12 |
| LED 3 | 21 |
| LED 4 | 22 |
| LED 5 | 24 |
| LED 6 | 25 |
| LED 7 | 26 |
| LED 8 | 27 |

### On resistor value

With 330 Ω and a red LED, the Pico's 3.3 V output sources about 4 mA peak. The
code then applies 12 % PWM, giving deliberately low brightness.

If it's too dim on stage, two levers in this order: **raise `BRILLANCE`** in
`code.py`, which is free and reversible; only then drop to 220 Ω. Don't go below
150 Ω — a Pico pin is rated for 12 mA.

> **Blue and white LEDs are a special case.** Their forward voltage is 3.0 to
> 3.2 V, essentially the Pico's 3.3 V. They'll be very dim whatever the resistor.
> Stick to red, yellow or standard green.

### Preparing an LED

The aim: the LED leaves the bench as a two-wire component with no bare resistor
anywhere in the enclosure.

1. **Use different wire colours for the two legs.** Solid for cathode (ground),
   striped for anode. Same on all eight — once heatshrunk you'll only see wires.
2. **Cut the anode — the long leg — to 5 mm.** Leave the cathode longer so you
   can still tell them apart.
3. **Slide the heatshrink on BEFORE soldering.** Two pieces, one per joint. This
   is the mistake everyone makes once.
4. **Solder the resistor end-to-end onto the anode.** Tin both, touch them
   together, heat for a second. No twisting needed.
5. **Solder the striped wire** to the far end of the resistor, and the solid wire
   to the cathode.
6. **Shrink both sleeves.** The anode sleeve should cover the whole resistor and
   overhang each end.

---

## 7. The LCD1602

| LCD pin | To |
|---|---|
| 1 VSS | ground rail |
| 2 VDD | pin 40 — VBUS, 5 V |
| 3 V0 | potentiometer wiper |
| 4 RS | pin 14 |
| 5 R/W | **ground rail** |
| 6 E | pin 15 |
| 7–10 D0–D3 | **nothing**, 4-bit mode |
| 11 D4 | pin 16 |
| 12 D5 | pin 17 |
| 13 D6 | pin 19 |
| 14 D7 | pin 20 |
| 15 A | pin 40 — VBUS |
| 16 K | ground rail |

### Contrast potentiometer

10 kΩ, three legs. The **middle** one is the wiper.

```
   VBUS ──────┤ │ │├────── ground rail
               └─┬─┘
                 └──────── LCD pin 3
```

The two outer legs are interchangeable; swapping them only reverses the
direction of travel.

**Without it the display is either solid black or completely blank.** It's the
number one cause of "my LCD doesn't work".

### Three things that matter

**R/W must go to ground.** That puts the LCD in write-only mode so it can never
drive 5 V back into a Pico input. This is what makes the 5 V / 3.3 V mix safe
here.

**No resistor on pin 15.** QAPASS 1602A modules already carry R8, marked `101`
for 100 Ω, on the back near pin K. On another model, check before connecting —
otherwise 220 Ω in series.

**Bridge on the module.** Pins 1, 5 and 16 all go to ground: link them directly
on the LCD so only one wire leaves. Same for 2 and 15 to VBUS. That takes you
from ten wires to eight, and the potentiometer straddles pins 1, 2 and 3 with no
flying leads.

---

## 8. Mounting the Pico

Don't solder wires straight to the Pico. Solder **two female headers to the
stripboard** and plug the Pico into them. All wiring lands on the board, never on
the module.

The day you want to replace the Pico, change a pin assignment or reclaim it for
something else, it lifts straight out. Twenty wires soldered to tightly-spaced
pads means an hour of desoldering and at least one lifted pad.

Headers cost 8 mm of height. If your enclosure is tight at the front — 27 mm —
soldering the Pico flat to the board is an acceptable trade: the board itself
stays modifiable.

**Solder the headers with the Pico plugged into them.** That keeps them square.
Freehand they end up skewed and won't fit anywhere.

---

## 9. Assembly order

Test each step before moving on.

1. **The ground rail and its link to pin 38.** Check continuity end to end.
2. **VBUS.** Check there is *no* continuity between the ground rail and 5 V — a
   short here stops the Pico booting.
3. **The LCD**, potentiometer included. On power-up a row of black blocks should
   appear: proof it's alive. Turn the pot until they fade.
4. **The LEDs, one at a time.** Test each with
   `printf 'S1\n' > /dev/pipedal-pico` and variants.
5. **The switches, one at a time.** `aseqdump -p XX:0` on the Pi shows the CCs
   going out.

---

## 10. Multimeter checks

Pico unplugged, before first power-up:

| Test | Expected |
|---|---|
| Ground rail ↔ pin 38 | continuity |
| Pin 38 ↔ pin 40 | **no** continuity |
| Each LED cathode ↔ rail | continuity |
| Each LED anode ↔ its pin | ~330 Ω |
| LCD 1, 5, 16 ↔ rail | continuity |
| LCD 2, 15 ↔ pin 40 | continuity |
| Two adjacent GPIO pins | **no** continuity |

The last one catches solder bridges, which are both the most common fault and the
hardest to see by eye on stripboard.

---

## 11. Wire count

| Destination | Wires to the board |
|---|---|
| 8 switches | 8 signal + 8 ground |
| 8 LEDs | 8 signal + 8 ground |
| LCD | 6 signal + 1 ground + 1 power |
| Potentiometer | 3 |
| **Total** | **42** |

Solid-core wire pulled from Cat 6 cable (23 AWG, 0.26 mm²) works well: it handles
several amps where the build draws 50 mA, it holds in a breadboard, its
insulation survives the iron, and eight colours make identification easy.

Pick a convention and write it down — brown for ground, orange for 5 V, say. Six
months from now, reopening the enclosure, you'll be glad not to have to buzz out
every wire.

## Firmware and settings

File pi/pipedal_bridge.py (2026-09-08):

#!/usr/bin/env python3
# ---------------------------------------------------------------------------
# pipedal_bridge.py - Demon de pont PiPedal -> Pico
#
# A INSTALLER SUR LE RASPBERRY PI, pas sur le Pico.
#
# Protocole PiPedal 2.0.110, releve par capture des trames websocket.
#
#   Enveloppe : tableau JSON  [entete]  ou  [entete, corps]
#
#   Requete sans argument (1 element) :
#     [{"message": "hello", "replyTo": 2}]
#   Requete avec argument (2 elements) :
#     [{"message": "monitorPort", "replyTo": 24},
#      {"instanceId": 16, "key": "FREQ", "updateRate": 0.0333}]
#   Reponse du serveur :
#     [{"reply": 2, "message": "ehlo"}, 20]
#
#   Diffusion sur changement (pas de replyTo, rien a acquitter) :
#     [{"message": "onPedalboardChanged"},
#      {"clientId": -1, "pedalboard": { ... "selectedSnapshot": 1 ... }}]
#
#   Message pousse avec accuse demande :
#     [{"replyTo": 996, "message": "onVuUpdate"}, {...}]
#   Le client doit repondre :
#     [{"reply": 996, "message": "onVuUpdate"}, true]
#
#   IMPORTANT : le client doit envoyer "hello" a la connexion pour etre
#   enregistre comme destinataire des diffusions.
#
#   L'index de snapshot est en BASE 0 cote PiPedal.
#   Le protocole serie vers le Pico est en BASE 1 (S1..S4).
#
# Protocole serie emis vers le Pico :
#   S<n>        snapshot actif, base 1
#   S-          aucun snapshot selectionne dans ce pedalboard
#   HB          battement de coeur, 1 Hz
#   N:<texte>   nom du pedalboard      -> LCD ligne 1
#   M:<texte>   nom du snapshot actif  -> LCD ligne 2
#   T:<note>:<cents>  accordeur, ex. T:E2:-12
#   T:-         accordeur, aucun signal
#   T:!         aucun accordeur dans le pedalboard
#
# Protocole serie recu du Pico :
#   A1 / A0     entree / sortie du mode accordeur
#   ?           le Pico demarre et reclame l'etat complet
#
# Dependances :
#   sudo apt install python3-serial
#   pip3 install websockets --break-system-packages
#
# Lancement :
#   python3 pipedal_bridge.py -v
# ---------------------------------------------------------------------------

import argparse
import asyncio
import json
import logging
import time
import unicodedata

import serial
import websockets


# ---------------------------------------------------------------------------
# Configuration
# ---------------------------------------------------------------------------

WS_URL = "ws://127.0.0.1:80/pipedal"      # chemin confirme par capture

PORT_SERIE = "/dev/pipedal-pico"
BAUD = 115200

PERIODE_HEARTBEAT = 1.0
BACKOFF_MIN = 0.5
BACKOFF_MAX = 10.0

# Repli si le serveur ne diffuse rien : redemander l'etat periodiquement.
# Mettre a 0 pour desactiver.
PERIODE_SONDAGE = 0.0

# Accordeur
URI_ACCORDEUR = "http://two-play.com/plugins/toob-tuner"
PORT_ACCORDEUR = "FREQ"
PERIODE_ACCORDEUR = 0.05     # secondes entre deux mesures cote PiPedal
DEBIT_ACCORDEUR = 0.09       # intervalle mini entre deux trames serie
PAS_CENTS = 2                # quantification, evite de saturer le LCD

NOTES = ("C", "C#", "D", "D#", "E", "F", "F#", "G", "G#", "A", "A#", "B")

log = logging.getLogger("bridge")

# Sentinelle : distingue "pas encore recu" de "aucun snapshot actif".
INCONNU = object()


def ascii_propre(texte):
    """Convertit un texte Unicode en ASCII sur pour le protocole serie.

    PiPedal accepte les noms Unicode, alors que le protocole du Pico est
    volontairement ASCII. Les accents sont translitteres (ex. "separe" pour
    "séparé") et les caracteres sans equivalent ASCII sont ignores.
    """
    if texte is None:
        return ""
    texte = unicodedata.normalize("NFKD", str(texte))
    return texte.encode("ascii", "ignore").decode("ascii")


# ---------------------------------------------------------------------------
# Lien serie vers le Pico
#
# Le Pico reinitialise son USB a chaque sauvegarde de code.py : le port
# disparait puis revient. Cette classe encaisse ca sans faire tomber le demon.
# ---------------------------------------------------------------------------

class LienPico:

    def __init__(self, port, baud):
        self.port = port
        self.baud = baud
        self.ser = None
        self._signale = False
        self._tampon = b""
        self._neuf = False

    def _ouvrir(self):
        if self.ser is not None:
            return True
        try:
            self.ser = serial.Serial(self.port, self.baud, timeout=0)
            self.ser.dtr = True       # sans DTR, le Pico ne lit rien
            log.info("Port serie ouvert : %s", self.port)
            self._signale = False
            self._neuf = True
            return True
        except (serial.SerialException, OSError) as e:
            self.ser = None
            if not self._signale:
                log.warning("Port serie indisponible (%s)", e)
                self._signale = True
            return False

    def _fermer(self):
        if self.ser is not None:
            try:
                self.ser.close()
            except Exception:
                pass
            self.ser = None
            log.warning("Port serie perdu, reouverture au prochain envoi")

    def reconnecte(self):
        """True une seule fois apres chaque (re)ouverture du port.

        Le Pico redemarre sans que PiPedal change d'etat : sans ce signal,
        le demon continuerait d'emettre uniquement des HB et le pedalier
        resterait aveugle jusqu'au prochain changement reel."""
        if self._neuf:
            self._neuf = False
            return True
        return False

    def lire(self):
        """Renvoie les lignes completes recues du Pico. Ne leve jamais."""
        if not self._ouvrir():
            return []
        try:
            n = self.ser.in_waiting
            if n:
                self._tampon += self.ser.read(n)
        except (serial.SerialException, OSError):
            self._fermer()
            return []

        lignes = []
        while b"\n" in self._tampon:
            brut, self._tampon = self._tampon.split(b"\n", 1)
            try:
                texte = brut.decode("ascii").strip()
            except UnicodeDecodeError:
                continue
            if texte:
                lignes.append(texte)
        return lignes

    def envoyer(self, trame):
        """Envoie une trame texte ASCII, saut de ligne ajoute. Ne leve jamais."""
        if not self._ouvrir():
            return False
        try:
            trame = ascii_propre(trame)
            self.ser.write((trame + "\n").encode("ascii"))
            return True
        except (UnicodeError, serial.SerialException, OSError):
            self._fermer()
            return False


# ---------------------------------------------------------------------------
# Etat courant, cache pour n'emettre que sur changement
# ---------------------------------------------------------------------------

class Etat:

    def __init__(self, lien):
        self.lien = lien
        # None      : aucun snapshot selectionne cote PiPedal
        # INCONNU   : on n'a pas encore recu l'information
        self.snapshot = INCONNU        # index base 0, ou None
        self.nom_pedalboard = None
        self.nom_snapshot = None
        self.instance = None       # instanceId du TooB Tuner
        self.mode_accordeur = False
        self.handle = None         # subscriptionHandle renvoye par PiPedal
        self.attente_handle = None # replyTo de notre monitorPort en cours
        self.compteur = 100
        self._derniere_note = None
        self._dernier_envoi = 0.0

    def maj_snapshot(self, index_base0, forcer=False):
        """index_base0 : index PiPedal, base 0.

        PiPedal renvoie -1 quand le pedalboard n'a aucun snapshot
        selectionne. Sans traitement dedie, le +1 donnerait S0, que le
        Pico rejetterait en silence en gardant l'ancien affichage."""
        if index_base0 is None:
            return                       # information absente : on ne touche a rien

        index = int(index_base0)
        if index < 0:
            index = None                 # aucun snapshot actif

        if not forcer and index == self.snapshot:
            return
        self.snapshot = index

        if index is None:
            self.lien.envoyer("S-")
            log.info("snapshot -> aucun")
        else:
            self.lien.envoyer("S%d" % (index + 1))
            log.info("snapshot -> %d", index + 1)

    def maj_nom(self, nom, forcer=False):
        if not nom:
            return
        if forcer or nom != self.nom_pedalboard:
            self.nom_pedalboard = nom
            # Le Pico ignore cette trame pour l'instant. Elle servira
            # quand un ecran sera cable.
            self.lien.envoyer("N:" + nom[:20])
            log.info("pedalboard -> %s", nom)

    def maj_nom_snapshot(self, nom, forcer=False):
        if not nom:
            return
        if forcer or nom != self.nom_snapshot:
            self.nom_snapshot = nom
            self.lien.envoyer("M:" + nom[:16])
            log.info("snapshot nomme -> %s", nom)

    # -- accordeur -----------------------------------------------------

    def _id(self):
        self.compteur += 1
        return self.compteur

    async def abonner(self, ws):
        """S'abonne au port FREQ du TooB Tuner du pedalboard courant."""
        if self.instance is None:
            self.lien.envoyer("T:!")
            log.warning("Aucun TooB Tuner dans ce pedalboard")
            return
        ident = self._id()
        self.attente_handle = ident
        await ws.send(trame_requete(ident, "monitorPort", {
            "instanceId": self.instance,
            "key": PORT_ACCORDEUR,
            "updateRate": PERIODE_ACCORDEUR,
        }))
        log.info("Accordeur : abonnement sur instance %s", self.instance)

    async def desabonner(self, ws):
        if self.handle is None:
            return
        await ws.send(json.dumps([{"message": "unmonitorPort"}, self.handle]))
        log.info("Accordeur : desabonnement")
        self.handle = None
        self.attente_handle = None
        self._derniere_note = None

    async def activer(self, ws, actif):
        if actif == self.mode_accordeur:
            return
        self.mode_accordeur = actif
        if actif:
            await self.abonner(ws)
        else:
            await self.desabonner(ws)

    def mesure(self, valeur):
        """Traduit une valeur FREQ en trame serie, avec limitation de debit."""
        if not self.mode_accordeur:
            return

        note, cents = note_et_cents(valeur)
        if note is not None:
            cents = int(round(cents / PAS_CENTS)) * PAS_CENTS
        courant = (note, cents)

        maintenant = time.monotonic()
        if courant == self._derniere_note:
            return
        if maintenant - self._dernier_envoi < DEBIT_ACCORDEUR:
            return

        self._derniere_note = courant
        self._dernier_envoi = maintenant
        if note is None:
            self.lien.envoyer("T:-")
        else:
            self.lien.envoyer("T:%s:%d" % (note, cents))

    def repousser(self):
        """Reemet l'etat connu, apres reconnexion."""
        if self.snapshot is not INCONNU:
            self.maj_snapshot(-1 if self.snapshot is None else self.snapshot,
                              forcer=True)
        if self.nom_pedalboard is not None:
            self.maj_nom(self.nom_pedalboard, forcer=True)
        if self.nom_snapshot is not None:
            self.maj_nom_snapshot(self.nom_snapshot, forcer=True)


# ---------------------------------------------------------------------------
# Protocole PiPedal
# ---------------------------------------------------------------------------

def analyser(brut):
    """Decoupe l'enveloppe. Renvoie (nom, corps, entete)."""
    try:
        paquet = json.loads(brut)
    except (ValueError, TypeError):
        return (None, None, {})

    if not isinstance(paquet, list) or not paquet:
        return (None, None, {})

    entete = paquet[0]
    if not isinstance(entete, dict):
        return (None, None, {})

    corps = paquet[1] if len(paquet) > 1 else None
    return (entete.get("message"), corps, entete)


def trame_requete(identifiant, nom, argument=None):
    """Requete client -> serveur. Un seul element si pas d'argument."""
    entete = {"message": nom, "replyTo": identifiant}
    if argument is None:
        return json.dumps([entete])
    return json.dumps([entete, argument])


def trame_accuse(identifiant, nom):
    """Accuse de reception d'un message pousse par le serveur."""
    return json.dumps([{"reply": identifiant, "message": nom}, True])


def note_et_cents(valeur):
    """FREQ du TooB Tuner : numero de note MIDI flottant, -1 si silence."""
    if valeur is None or valeur < 0:
        return (None, 0)
    entier = int(round(valeur))
    cents = int(round((valeur - entier) * 100))
    if not (0 <= entier <= 127):
        return (None, 0)
    return (NOTES[entier % 12] + str(entier // 12 - 1), cents)


def instance_accordeur(pedalboard):
    """InstanceId du TooB Tuner dans le pedalboard courant, ou None.

    Il change d'un pedalboard a l'autre : ne jamais coder 16 en dur."""
    items = pedalboard.get("items")
    if not isinstance(items, list):
        return None
    for item in items:
        if isinstance(item, dict) and item.get("uri") == URI_ACCORDEUR:
            return item.get("instanceId")
    return None


def nom_du_snapshot(pedalboard):
    """Nom du snapshot selectionne. La liste contient des trous (null)."""
    index = pedalboard.get("selectedSnapshot")
    liste = pedalboard.get("snapshots")
    if index is None or not isinstance(liste, list):
        return None
    if not (0 <= index < len(liste)):
        return None
    entree = liste[index]
    if not isinstance(entree, dict):
        return None
    return entree.get("name")


def extraire(nom, corps):
    """
    Traduit un message en dict d'etat.
    Cles possibles : "snapshot" (base 0), "nom", "nom_snapshot".
    Renvoie {} si le message ne nous concerne pas.
    """
    if nom in ("onVuUpdate", "onMonitorPortOutput"):
        return {}

    # Diffusion sur changement : l'index est dans body.pedalboard
    if nom == "onPedalboardChanged":
        if not isinstance(corps, dict):
            return {}
        pb = corps.get("pedalboard")
        if not isinstance(pb, dict):
            return {}
        return {
            "snapshot": pb.get("selectedSnapshot"),
            "nom": pb.get("name"),
            "nom_snapshot": nom_du_snapshot(pb),
            "instance": instance_accordeur(pb),
        }

    # Reponse a notre requete : le pedalboard est a la racine du corps
    if nom == "currentPedalboard":
        if not isinstance(corps, dict):
            return {}
        return {
            "snapshot": corps.get("selectedSnapshot"),
            "nom": corps.get("name"),
            "nom_snapshot": nom_du_snapshot(corps),
            "instance": instance_accordeur(corps),
        }

    return {}


# ---------------------------------------------------------------------------
# Boucles asynchrones
# ---------------------------------------------------------------------------

async def battement(lien, etat):
    """Signal de vie vers le Pico. Son absence fait clignoter les LED.

    Sert aussi a detecter le redemarrage du Pico, pour lui renvoyer
    l'etat complet."""
    while True:
        lien.envoyer("HB")
        if lien.reconnecte():
            log.info("Pico (re)connecte : renvoi de l'etat complet")
            etat.repousser()
        await asyncio.sleep(PERIODE_HEARTBEAT)


async def ecouter_pico(lien, file):
    """Remonte les commandes envoyees par le Pico sur le port serie."""
    while True:
        for ligne in lien.lire():
            log.debug("Pico -> %s", ligne)
            await file.put(ligne)
        await asyncio.sleep(0.02)


async def commandes(ws, etat, file):
    """Applique les commandes du Pico sur la connexion courante."""
    while True:
        cmd = await file.get()
        if cmd == "A1":
            await etat.activer(ws, True)
        elif cmd == "A0":
            await etat.activer(ws, False)
        elif cmd == "?":
            # Le Pico vient de demarrer : il est forcement en mode normal.
            # Sans ce desabonnement, un reflashage effectue en mode
            # accordeur laisserait le demon abonne a FREQ pour rien.
            log.info("Le Pico reclame l'etat")
            await etat.activer(ws, False)
            etat.repousser()


async def sondage(ws):
    """Repli optionnel : redemander l'etat au lieu d'attendre la diffusion."""
    ident = 1000
    while True:
        await asyncio.sleep(PERIODE_SONDAGE)
        ident += 1
        try:
            await ws.send(trame_requete(ident, "currentPedalboard"))
        except Exception:
            return


async def session(etat, file):
    """Une connexion websocket, de l'ouverture a la coupure."""
    async with websockets.connect(WS_URL, ping_interval=20,
                                  max_size=8 * 1024 * 1024) as ws:
        log.info("Connecte a %s", WS_URL)

        # Sans ce "hello", le serveur ne nous enregistre pas comme client
        # et ne nous enverra aucune diffusion.
        await ws.send(trame_requete(1, "hello"))

        # Etat initial, sinon on reste aveugle jusqu'au premier changement.
        await ws.send(trame_requete(2, "currentPedalboard"))

        etat.repousser()

        # Une nouvelle connexion invalide l'ancien abonnement.
        etat.handle = None
        etat.attente_handle = None
        if etat.mode_accordeur:
            await etat.abonner(ws)

        taches = [asyncio.create_task(commandes(ws, etat, file))]
        if PERIODE_SONDAGE > 0:
            taches.append(asyncio.create_task(sondage(ws)))
            log.info("Sondage actif (%.2f s)", PERIODE_SONDAGE)

        try:
            async for brut in ws:
                nom, corps, entete = analyser(brut)
                if nom is None:
                    continue

                # Certains messages exigent un accuse, sinon le serveur
                # considere le client bloque et cesse d'emettre.
                ident = entete.get("replyTo")
                if ident is not None:
                    await ws.send(trame_accuse(ident, nom))

                # Reponse a notre monitorPort : on recupere le handle.
                if (nom == "monitorPort"
                        and etat.attente_handle is not None
                        and entete.get("reply") == etat.attente_handle):
                    etat.handle = corps
                    etat.attente_handle = None
                    log.info("Accordeur : handle %s", corps)
                    continue

                # Mesure de l'accordeur.
                if nom == "onMonitorPortOutput":
                    if (isinstance(corps, dict)
                            and corps.get("subscriptionHandle") == etat.handle):
                        etat.mesure(corps.get("value"))
                    continue

                champs = extraire(nom, corps)
                if not champs:
                    if nom != "onVuUpdate":
                        log.debug("<- %s", nom)
                    continue

                log.debug("<- %s %s", nom, champs)
                etat.maj_snapshot(champs.get("snapshot"))
                etat.maj_nom(champs.get("nom"))
                etat.maj_nom_snapshot(champs.get("nom_snapshot"))

                # Le TooB Tuner peut changer d'instanceId avec le pedalboard.
                instance = champs.get("instance")
                if instance != etat.instance:
                    etat.instance = instance
                    if etat.mode_accordeur:
                        etat.handle = None
                        await etat.abonner(ws)
        finally:
            for t in taches:
                t.cancel()


async def principale():
    lien = LienPico(PORT_SERIE, BAUD)
    etat = Etat(lien)

    file = asyncio.Queue()
    asyncio.create_task(battement(lien, etat))
    asyncio.create_task(ecouter_pico(lien, file))

    backoff = BACKOFF_MIN
    while True:
        try:
            await session(etat, file)
            log.warning("Websocket ferme par le serveur")
            backoff = BACKOFF_MIN
        except Exception as e:
            log.warning("Connexion perdue (%s), nouvel essai dans %.1f s",
                        e, backoff)

        await asyncio.sleep(backoff)
        backoff = min(backoff * 2, BACKOFF_MAX)


def main():
    ap = argparse.ArgumentParser(description="Pont PiPedal vers pedalier Pico")
    ap.add_argument("-v", "--verbeux", action="store_true",
                    help="affiche le detail des trames")
    args = ap.parse_args()

    logging.basicConfig(
        level=logging.DEBUG if args.verbeux else logging.INFO,
        format="%(asctime)s %(levelname)-7s %(message)s",
    )
    if args.verbeux:
        logging.getLogger("websockets").setLevel(logging.INFO)

    try:
        asyncio.run(principale())
    except KeyboardInterrupt:
        pass


if __name__ == "__main__":
    main()

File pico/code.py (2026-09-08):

# ---------------------------------------------------------------------------
# code.py - Pedalier MIDI PiPedal
#
# 8 footswitches / 8 LEDs / 1 afficheur LCD1602.
#   S1..S4 : snapshots, CC 102..105, LED en selection exclusive
#   F1/F2  : preset precedent / suivant, CC 110 et 111, LED pendant le
#            chargement
#   F3     : bascule accordeur, CC 112, LED allumee tant que le mode dure
#   F4     : generique, CC 113, LED en flash de confirmation
#
# Les LED des snapshots ne sont PAS allumees a l'appui : elles attendent
# la confirmation du Raspberry Pi (module retour_pipedal). Repli optimiste
# a 200 ms si le Pi ne repond pas.
# ---------------------------------------------------------------------------

import time

import board
import digitalio
import pwmio
import usb_midi
import adafruit_midi
from adafruit_midi.control_change import ControlChange

import ecran
import retour_pipedal as retour


# ---------------------------------------------------------------------------
# Configuration materielle
#
# GP0..GP7   switches
# GP8, GP9   LED 1 et 2          (cablage existant, ne pas deplacer)
# GP10..GP15 LCD1602 en 4 bits
# GP16..GP21 LED 3 a 8
# ---------------------------------------------------------------------------

# Ordre : S1, S2, S3, S4, F1, F2, F3, F4
BROCHES_SWITCHES = (
    board.GP0, board.GP1, board.GP2, board.GP3,
    board.GP4, board.GP5, board.GP6, board.GP7,
)

BROCHES_LEDS = (
    board.GP8,  board.GP9,  board.GP16, board.GP17,
    board.GP18, board.GP19, board.GP20, board.GP21,
)

# Egalisation logicielle par canal, en pourcentage de duty.
# BRILLANCE[i] s'applique a BROCHES_LEDS[i] : garder le meme ordre.
BRILLANCE = (1, 16, 16, 6, 3, 3, 3, 3)

# LCD1602 en mode 4 bits. R/W du LCD doit etre cable a la masse.
LCD_RS = board.GP10
LCD_EN = board.GP11
LCD_D4 = board.GP12
LCD_D5 = board.GP13
LCD_D6 = board.GP14
LCD_D7 = board.GP15

FREQUENCE_PWM = 2000        # Hz, au-dessus du seuil de scintillement

NB_SNAPSHOTS = 4            # S1..S4
NB_SWITCHES = 8

CC_SNAPSHOTS = (102, 103, 104, 105)
CC_GENERIQUES = (110, 111, 112, 113)
CANAL_MIDI = 0              # canal 1 en notation humaine

ANTIREBOND = 0.02           # secondes
DUREE_FLASH = 0.12          # secondes, confirmation visuelle F2..F4

# Rang arriere, de gauche a droite :
#   F1  preset precedent   CC 110
#   F2  preset suivant     CC 111
#   F3  accordeur          CC 112
#   F4  libre              CC 113
#
# A lier dans PiPedal :
#   prevProgram -> CC 110      nextProgram -> CC 111
# Optionnel : CC 112 sur le MUTE du TooB Tuner, pour couper le son et
# afficher l'accordeur d'un seul geste.

# LED allumee pendant le chargement, qui peut durer une a deux secondes
# avec un modele NAM.
SWITCHES_PRESET = (4, 5)

# LED allumee tant que le mode accordeur dure, au lieu de flasher.
SWITCH_ACCORDEUR = 6


# ---------------------------------------------------------------------------
# MIDI
# ---------------------------------------------------------------------------

midi = adafruit_midi.MIDI(
    midi_out=usb_midi.ports[1],
    out_channel=CANAL_MIDI,
)


# ---------------------------------------------------------------------------
# LEDs
# ---------------------------------------------------------------------------

_leds = []
for broche in BROCHES_LEDS:
    _leds.append(pwmio.PWMOut(broche, frequency=FREQUENCE_PWM, duty_cycle=0))


def led(index, allumee):
    """Allume ou eteint une LED, a la brillance calibree du canal."""
    if allumee:
        _leds[index].duty_cycle = int(65535 * BRILLANCE[index] / 100)
    else:
        _leds[index].duty_cycle = 0


def allumer_exclusif(index):
    """Selection exclusive sur S1..S4. index=None eteint le groupe."""
    for i in range(NB_SNAPSHOTS):
        led(i, index is not None and i == index)


def eteindre_tout():
    for i in range(NB_SWITCHES):
        led(i, False)


# ---------------------------------------------------------------------------
# Switches
# ---------------------------------------------------------------------------

_switches = []
for broche in BROCHES_SWITCHES:
    sw = digitalio.DigitalInOut(broche)
    sw.direction = digitalio.Direction.INPUT
    sw.pull = digitalio.Pull.UP          # actif a l'etat bas
    _switches.append(sw)

_etat_switch = [True] * NB_SWITCHES      # True = relache (pull-up)
_dernier_changement = [0.0] * NB_SWITCHES
_fin_flash = [0.0] * NB_SWITCHES
_mode_accordeur = False


def cc_du_switch(index):
    if index < NB_SNAPSHOTS:
        return CC_SNAPSHOTS[index]
    return CC_GENERIQUES[index - NB_SNAPSHOTS]


def on_press(index):
    """Appui detecte."""
    global _mode_accordeur

    midi.send(ControlChange(cc_du_switch(index), 127))

    if index < NB_SNAPSHOTS:
        # On n'allume PAS ici. On arme l'attente de confirmation du Pi.
        retour.appui(index)
        return

    if index in SWITCHES_PRESET:
        # La LED s'eteindra quand le Pi annoncera le nouveau nom.
        retour.attente_changement(index)
        return

    if index == SWITCH_ACCORDEUR:
        # Bascule locale. Le demon s'abonne ou se desabonne du port FREQ.
        _mode_accordeur = not _mode_accordeur
        led(index, _mode_accordeur)
        retour.envoyer("A1" if _mode_accordeur else "A0")
        ecran.mode_accordeur(_mode_accordeur)
        return

    # F2..F4 : flash local, aucun etat a synchroniser.
    led(index, True)
    _fin_flash[index] = time.monotonic() + DUREE_FLASH


def on_release(index):
    """Relachement. Indispensable : PiPedal exige un CC 0 pour re-armer
    un binding en 'Trigger on rising edge'."""
    midi.send(ControlChange(cc_du_switch(index), 0))


def scruter():
    """Lecture antirebond des 8 switches."""
    maintenant = time.monotonic()
    for i in range(NB_SWITCHES):
        niveau = _switches[i].value
        if niveau == _etat_switch[i]:
            continue
        if maintenant - _dernier_changement[i] < ANTIREBOND:
            continue

        _etat_switch[i] = niveau
        _dernier_changement[i] = maintenant

        if niveau is False:          # front descendant = appui
            on_press(i)
        else:
            on_release(i)


def entretenir_flash():
    maintenant = time.monotonic()
    for i in range(NB_SNAPSHOTS, NB_SWITCHES):
        if i == SWITCH_ACCORDEUR or i in SWITCHES_PRESET:
            continue
        if _fin_flash[i] and maintenant >= _fin_flash[i]:
            _fin_flash[i] = 0.0
            led(i, False)


# ---------------------------------------------------------------------------
# Demarrage
# ---------------------------------------------------------------------------

eteindre_tout()

# L'ecran est un confort : s'il ne repond pas, le pedalier fonctionne
# quand meme, on passe simplement None a retour.init().
ecran_ok = ecran.init(LCD_RS, LCD_EN, LCD_D4, LCD_D5, LCD_D6, LCD_D7)
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

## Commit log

2026-09-08 fix: gérer les pedalboards sans snapshot et les index hors plage
    PiPedal renvoie selectedSnapshot: -1 quand le pedalboard courant n'a
    aucun snapshot défini. Le démon calculait -1 + 1 = 0 et émettait S0,
    que le Pico rejetait silencieusement puisqu'il n'accepte que la plage
    0..3. Résultat : LED et écran figés sur l'état précédent, et cache du
    démon désynchronisé de l'affichage réel, ce qui faussait les
    changements suivants.
    Même symptôme pour les snapshots 5 et 6, que PiPedal gère mais que le
    pédalier ne peut pas représenter avec quatre LED.
    Démon
    - Etat.snapshot distingue trois états au lieu de deux : INCONNU (rien
    reçu), None (aucun snapshot actif), index base 0.
    -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
    [pipedal_bridge.py, retour_pipedal.py]
2026-09-08 fix: évite les déconnexions causées par les caractères accentués dans les noms de preset
    Corrige l’encodage des messages contenant des caractères non ASCII, notamment « é », afin d’éviter les erreurs et les reconnexions du service PiPedal.
    [pipedal_bridge.py]
2026-09-08 docs: remove obsolete expression device mention
2026-09-08 docs: add editable V1 hardware wiring diagram
2026-09-08 Paramétrage de la puissance des LEDS
2026-09-08 Add 3D files for the box
    [case.SLDPRT, enclosure.STL, lid.STL]
2026-09-08 Update README.fr.md with 3D files and images
    Added information about 3D printing files and included images.
2026-09-08 Bold 3D print files availability in README
    Make the availability of 3D print files bold in the README.
